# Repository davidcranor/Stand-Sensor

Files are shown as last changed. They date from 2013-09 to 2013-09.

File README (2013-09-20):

Stand-Sensor

Design files for accelerometer-based sitting/standing sensor and electrolaminate driver.  Built on Leaflabs' Maple.

Make sure that you have my hacked up version of the Wire library installed, as we need repeated start I2C. To install
it, make  backup of the old files and copy my Wire.cpp and Wire.h over them in the 

MapleIDE.app/Contents/Resources/Java/libraries/Wire/

directory (If you're on Mac).  This is a gross hack, sorry.
  
When uploading firmware, remember to build/install the Maple Mini target.

BOM is here:
https://docs.google.com/spreadsheet/ccc?key=0AkMyKIrUOd24dHlMcE16TWFrMjVCWlNEYzV1VXQ2dXc&usp=sharing

David Cranor
September 2013
cranor at media .mit dot edu

v1 notes/errata:

-DO NOT connect VCC-GND side of the switch when populating.
-USB port not close enough to edge on PCB
-Fix R12 to not trigger under-voltage protection when running off of battery power.  See datasheet for TPS61200.
-Fix mounting hole pattern to actually be symmetrical
-The leakage current in the currently specced D1 is too high, which caused some problems with the NFET power
 source switch.  Get one with a reasonable leakage current on next order.
-The PCB is slightly larger than the slot on the enclosure will allow.

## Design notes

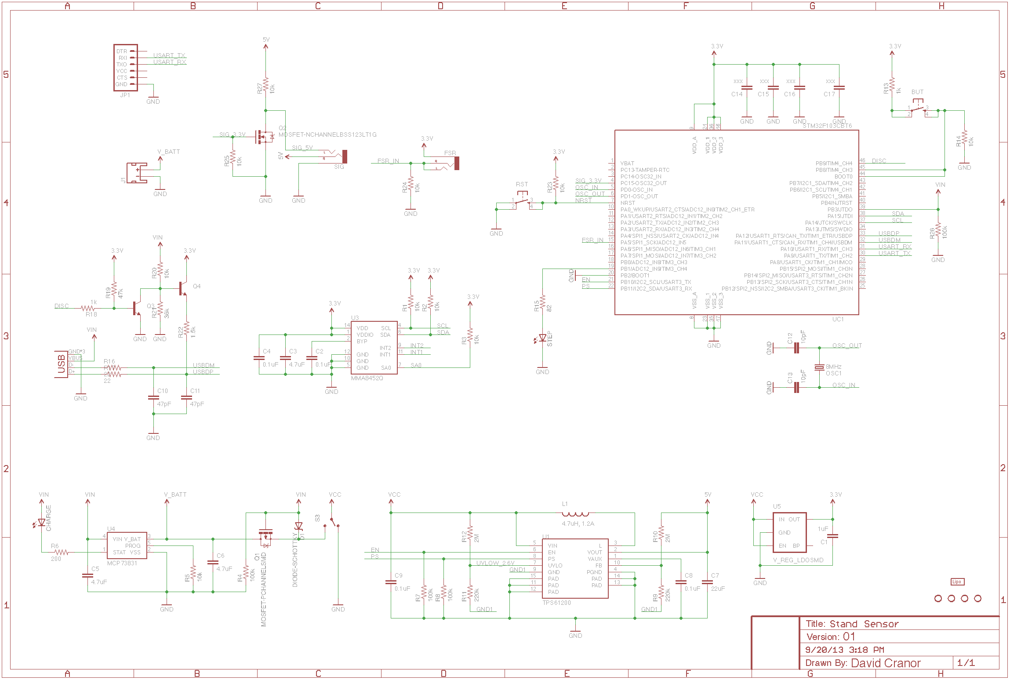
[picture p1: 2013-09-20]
Hardware/Stand Sensor.png

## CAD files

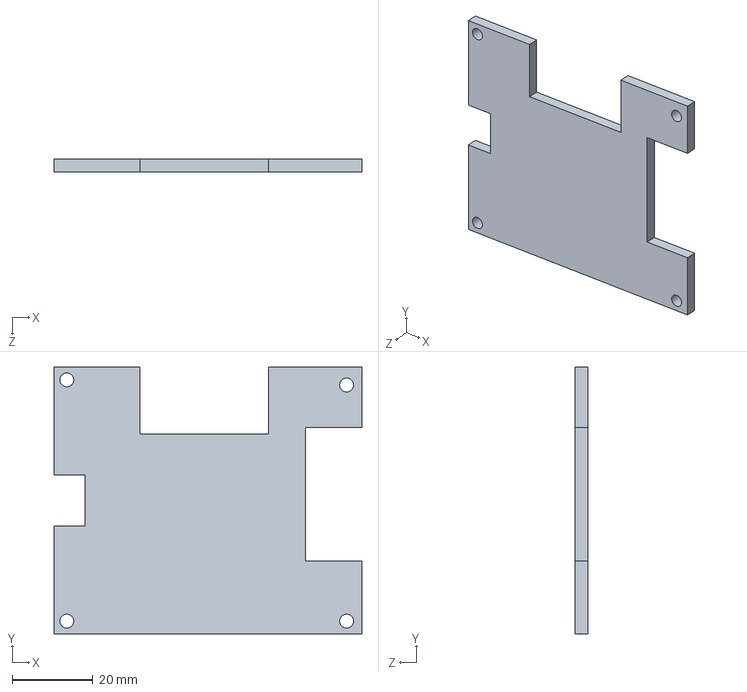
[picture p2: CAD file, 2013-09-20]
Enclosure/Stand Sensor Top Plate.SLDPRT
76.2 x 66.0 x 3.17 mm

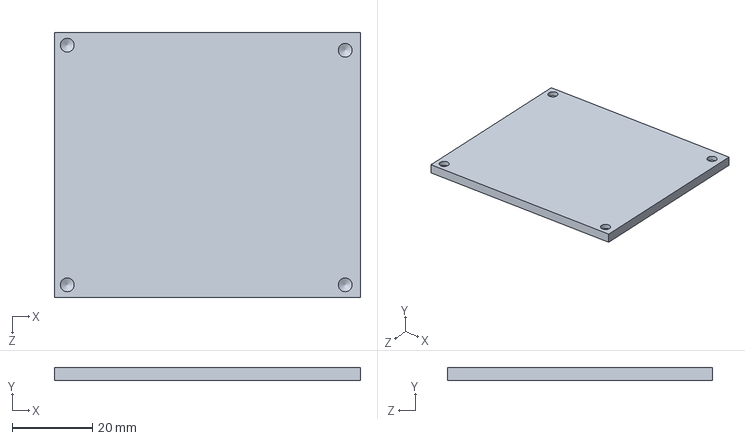
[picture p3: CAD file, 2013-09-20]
Enclosure/Stand Sensor Bottom Plate.SLDPRT
76.2 x 3.17 x 66.0 mm

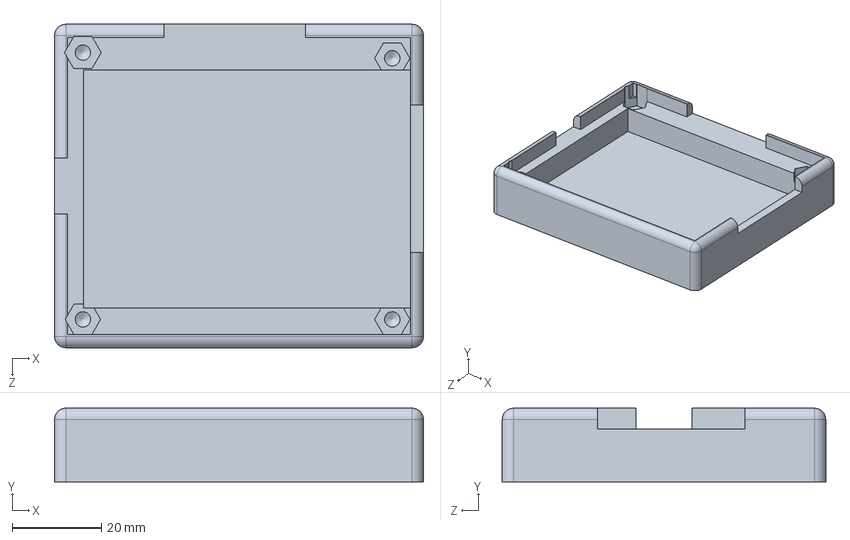
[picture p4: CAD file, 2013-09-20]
Enclosure/Stand Sensor Case.SLDPRT
82.5 x 16.5 x 72.4 mm

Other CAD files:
Enclosure/Stand Sensor Bottom Plate.DXF
Enclosure/Stand Sensor Bottom Plate.SLDDRW
Enclosure/Stand Sensor Case.STL
Enclosure/Stand Sensor Top Plate.DXF
Enclosure/Stand Sensor Top Plate.SLDDRW

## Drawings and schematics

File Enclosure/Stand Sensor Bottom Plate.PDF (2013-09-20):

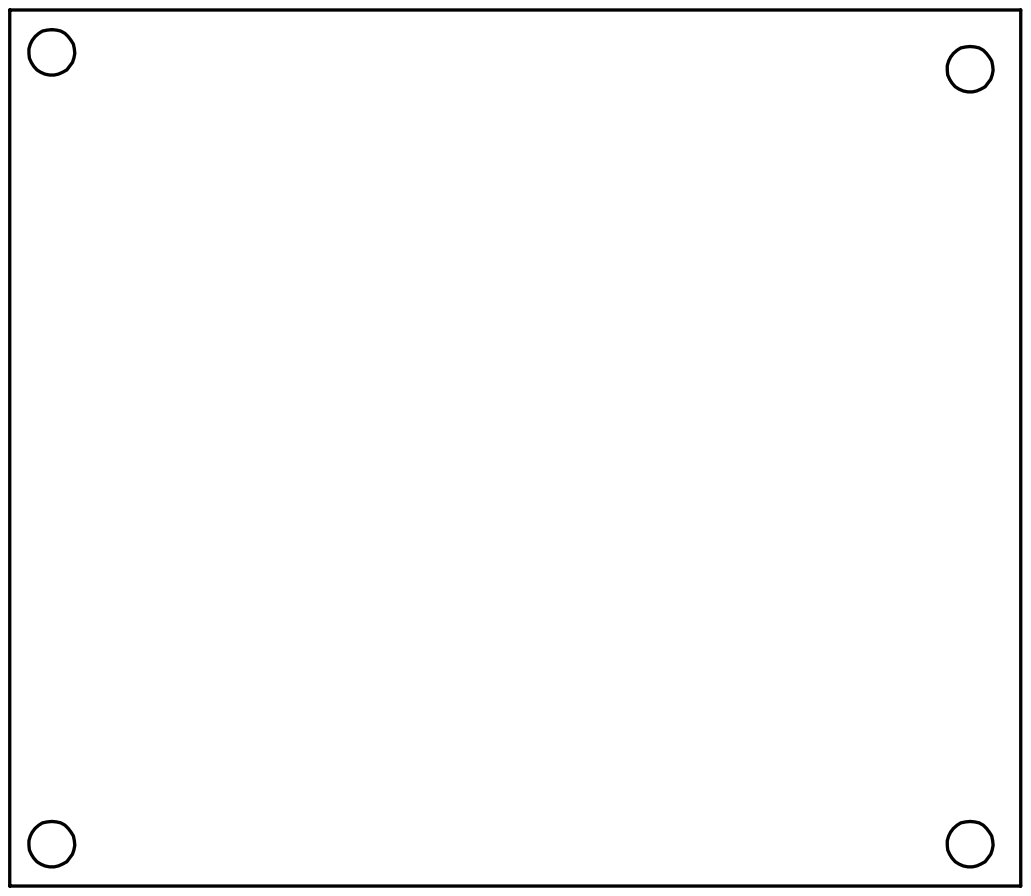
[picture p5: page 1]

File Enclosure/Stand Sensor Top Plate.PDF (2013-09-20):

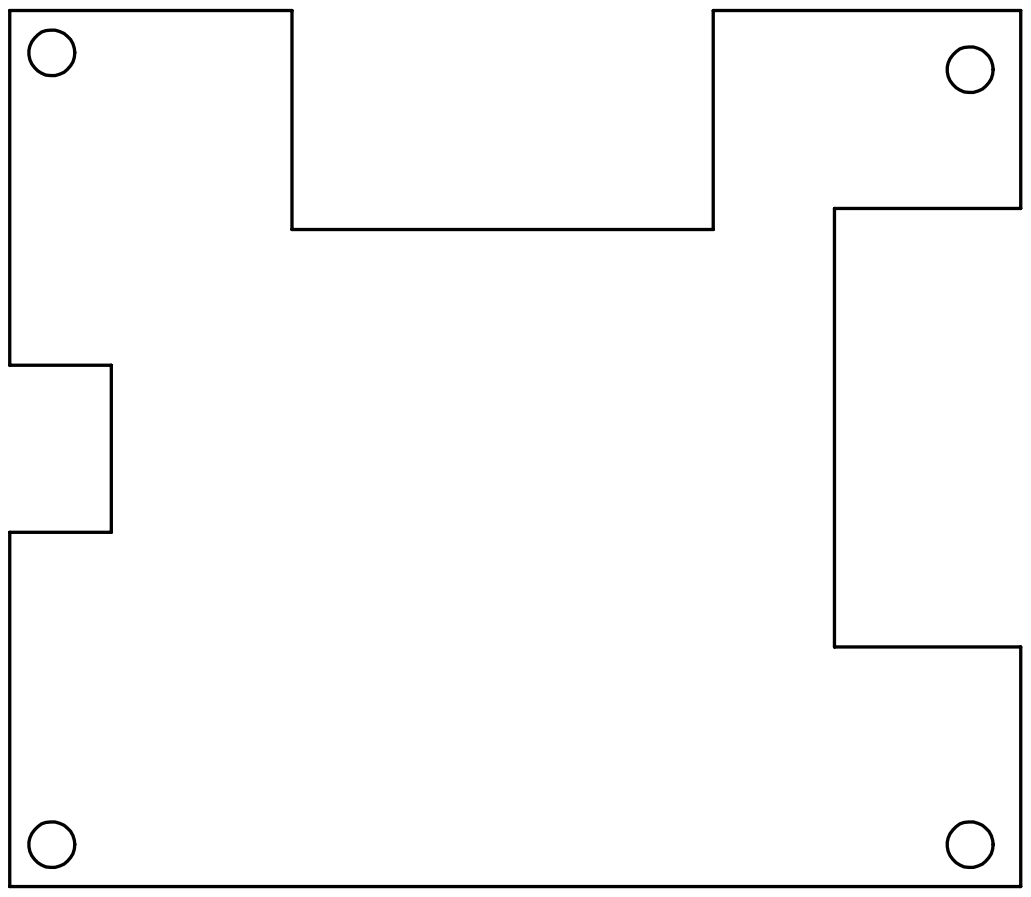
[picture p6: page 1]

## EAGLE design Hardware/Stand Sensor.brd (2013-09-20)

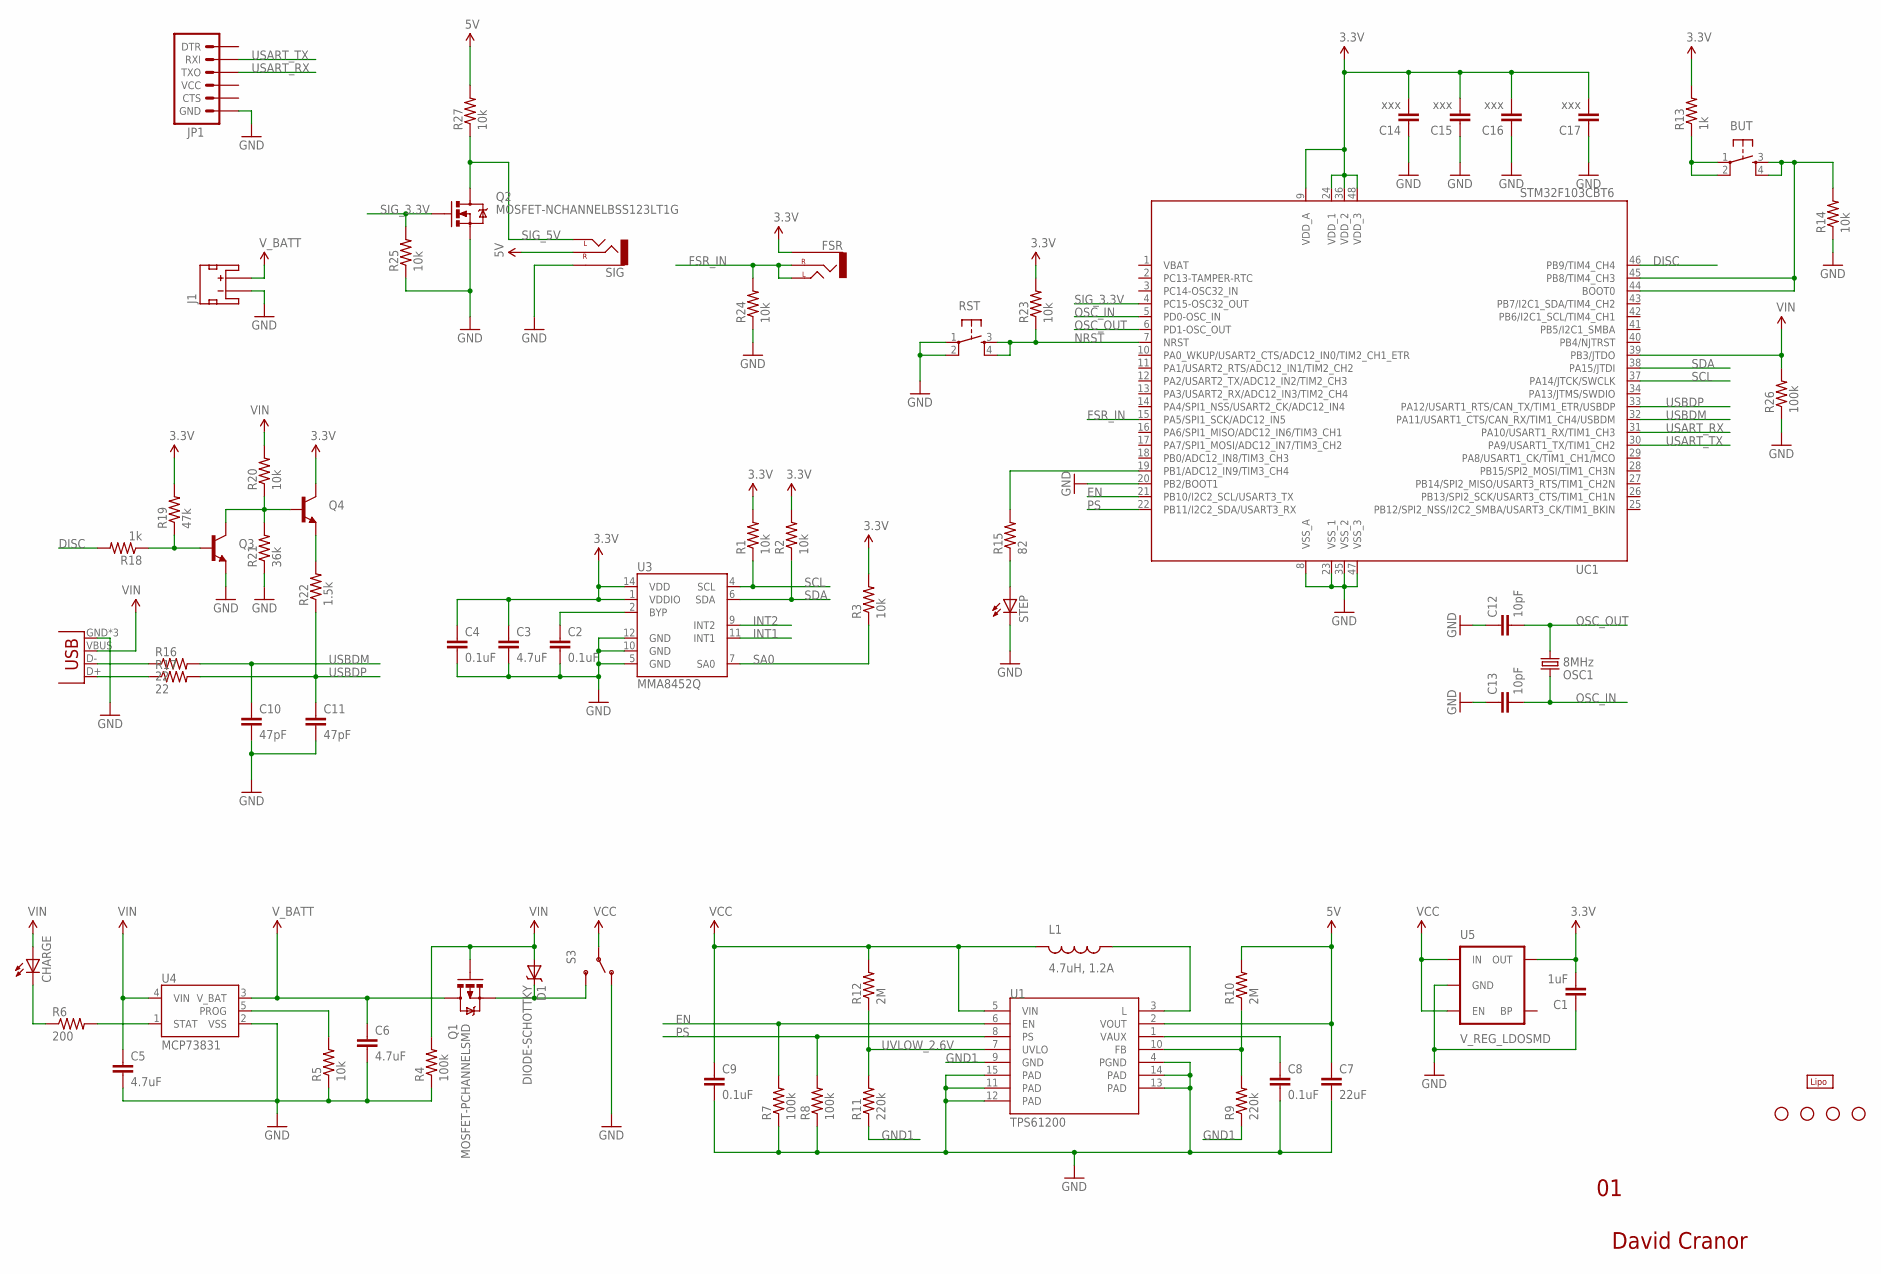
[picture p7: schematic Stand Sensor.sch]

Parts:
BUT: TAC_SWITCHSMD; TACTILE_SWITCH_SMD
C1: 1uF; 1206
C2, C4, C8, C9: 0.1uF; 1206
C3, C5, C6: 4.7uF; 1206
C7: 22uF; 1206
C10, C11: 47pF; 1206
C12, C13: 10pF; 1206
C14, C15, C16, C17: xxx; 1206
CHARGE: LED1206; LED-1206
D1: DIODE-SCHOTTKY; SOD-523
FSR: AUDIO-JACKPTH; AUDIO-JACK
J1: JST_2MM_MALE; JST-2-SMD
JP1: ARDUINO_SERIAL_PROGRAMSMD; 1X06-SMD
L1: 4.7uH, 1.2A; CDRH2D09
OSC1: 8MHz; CRYSTAL-SMD-5X3
Q1: MOSFET-PCHANNELSMD; SOT23-3
Q2: MOSFET-NCHANNELBSS123LT1G; SOT23
Q3, Q4: TRANSISTOR_NPNSOT23; SOT23
R1, R2, R3, R5, R14, R20, R23, R24, R25, R27: 10k; 1206
R4, R7, R8, R26: 100k; 1206
R6: 200; 1206
R9, R11: 220k; 1206
R10, R12: 2M; 1206
R13, R18: 1k; 1206
R15: 82; 1206
R16, R17: 22; 1206
R19: 47k; 1206
R21: 36k; 1206
R22: 1.5k; 1206
RST: TAC_SWITCHSMD; TACTILE_SWITCH_SMD
S3: SWITCH-SPDTSMD; AYZ0202
SIG: AUDIO-JACKPTH; AUDIO-JACK
STANDOFF1, STANDOFF2, STANDOFF3, STANDOFF4: STAND-OFF
STEP: LED1206; LED-1206
U1: TPS61200; QFN-10_PAD
U3: MMA8452Q; QFN-16_0.5MM
U4: MCP73831; SOT23-5
U5: V_REG_LDOSMD; SOT23-5
U$1: LIPO-OUTLINE2000; LIPO-2000
UC1: STM32F103CBT6; LQFP48
USB: USB-MICROB

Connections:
3.3V: C1.2, C3.1, C4.1, C14.2, C15.2, C16.2, C17.2, FSR.SLEEVE, Q4.3 (C), R1.2, R2.2, R3.2, R13.2, R19.2, R23.2, U3.1 (VDDIO), U3.14 (VDD), U5.5 (OUT), UC1.9 (VDD_A), UC1.24 (VDD_1), UC1.36 (VDD_2), UC1.48 (VDD_3)
5V: C7.1, R10.2, R27.2, SIG.RING (RIGHT), U1.2 (VOUT)
D+: R17.1, USB.D+
D-: R16.1, USB.D-
DISC: R18.2, UC1.46 (PB9/TIM4_CH4)
EN: R7.2, U1.6 (EN), UC1.21 (PB10/I2C2_SCL/USART3_TX)
FSR_IN: FSR.RING (RIGHT), FSR.TIP (LEFT), R24.2, UC1.15 (PA5/SPI1_SCK/ADC12_IN5)
GND: C1.1, C2.2, C3.2, C4.2, C5.2, C6.2, C7.2, C8.2, C9.2, C10.2, C11.2, C12.1, C13.1, C14.1, C15.1, C16.1, C17.1, J1.1 (-), JP1.6 (GND), Q2.2 (S), Q3.2 (E), R4.1, R5.1, R7.1, R8.1, R14.1, R21.1, R24.1, R25.1, R26.1, RST.1, RST.2, S3.1 (O), SIG.SLEEVE, STEP.C, U1.4 (PGND), U1.11 (PAD), U1.12 (PAD), U1.13 (PAD), U1.14 (PAD), U1.15 (PAD), U3.5 (GND), U3.10 (GND), U3.12 (GND), U4.2 (VSS), U5.2 (GND), UC1.8 (VSS_A), UC1.20 (PB2/BOOT1), UC1.23 (VSS_1), UC1.35 (VSS_2), UC1.47 (VSS_3), USB.GND, USB.MT1 (GND), USB.MT2 (GND)
GND1: R9.1, R11.1, U1.9 (GND)
INT1: U3.11 (INT1)
INT2: U3.9 (INT2)
unnamed: C2.1, U3.2 (BYP)
unnamed: L1.P$1 (1), U1.3 (L)
unnamed: R5.2, U4.5 (PROG)
unnamed: R6.2, U4.1 (STAT)
unnamed: CHARGE.C, R6.1
unnamed: D1.C, Q1.2 (S), S3.3 (S)
unnamed: C8.1, U1.1 (VAUX)
unnamed: R9.2, R10.1, U1.10 (FB)
unnamed: R15.2, UC1.19 (PB1/ADC12_IN9/TIM3_CH4)
unnamed: BUT.3, BUT.4, R14.2, UC1.44 (BOOT0), UC1.45 (PB8/TIM4_CH3)
unnamed: R15.1, STEP.A
unnamed: BUT.1, BUT.2, R13.1
unnamed: Q3.1 (B), R18.1, R19.1
unnamed: Q3.3 (C), Q4.1 (B), R20.1, R21.2
unnamed: Q4.2 (E), R22.2
NRST: R23.1, RST.3, RST.4, UC1.7 (NRST)
OSC_IN: C13.2, OSC1.3 (2), UC1.5 (PD0-OSC_IN)
OSC_OUT: C12.2, OSC1.1, UC1.6 (PD1-OSC_OUT)
PS: R8.2, U1.8 (PS), UC1.22 (PB11/I2C2_SDA/USART3_RX)
SA0: R3.1, U3.7 (SA0)
SCL: R1.1, U3.4 (SCL), UC1.37 (PA14/JTCK/SWCLK)
SDA: R2.1, U3.6 (SDA), UC1.38 (PA15/JTDI)
SIG_3.3V: Q2.1 (G), R25.2, UC1.4 (PC15-OSC32_OUT)
SIG_5V: Q2.3 (D), R27.1, SIG.TIP (LEFT)
USART_RX: JP1.3 (TXO), UC1.31 (PA10/USART1_RX/TIM1_CH3)
USART_TX: JP1.2 (RXI), UC1.30 (PA9/USART1_TX/TIM1_CH2)
USBDM: C10.1, R16.2, UC1.32 (PA11/USART1_CTS/CAN_RX/TIM1_CH4/USBDM)
USBDP: C11.1, R17.2, R22.1, UC1.33 (PA12/USART1_RTS/CAN_TX/TIM1_ETR/USBDP)
UVLOW_2.6V: R11.2, R12.1, U1.7 (UVLO)
VBAT: UC1.1 (VBAT)
VCC: C9.1, L1.P$2 (2), R12.2, S3.2, U1.5 (VIN), U5.1 (IN), U5.3 (EN)
VIN: C5.1, CHARGE.A, D1.A, Q1.1 (G), R4.2, R20.2, R26.2, U4.4 (VIN), UC1.39 (PB3/JTDO), USB.VBUS
V_BATT: C6.1, J1.2 (+), Q1.3 (D), U4.3 (V_BAT)

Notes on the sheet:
David Cranor

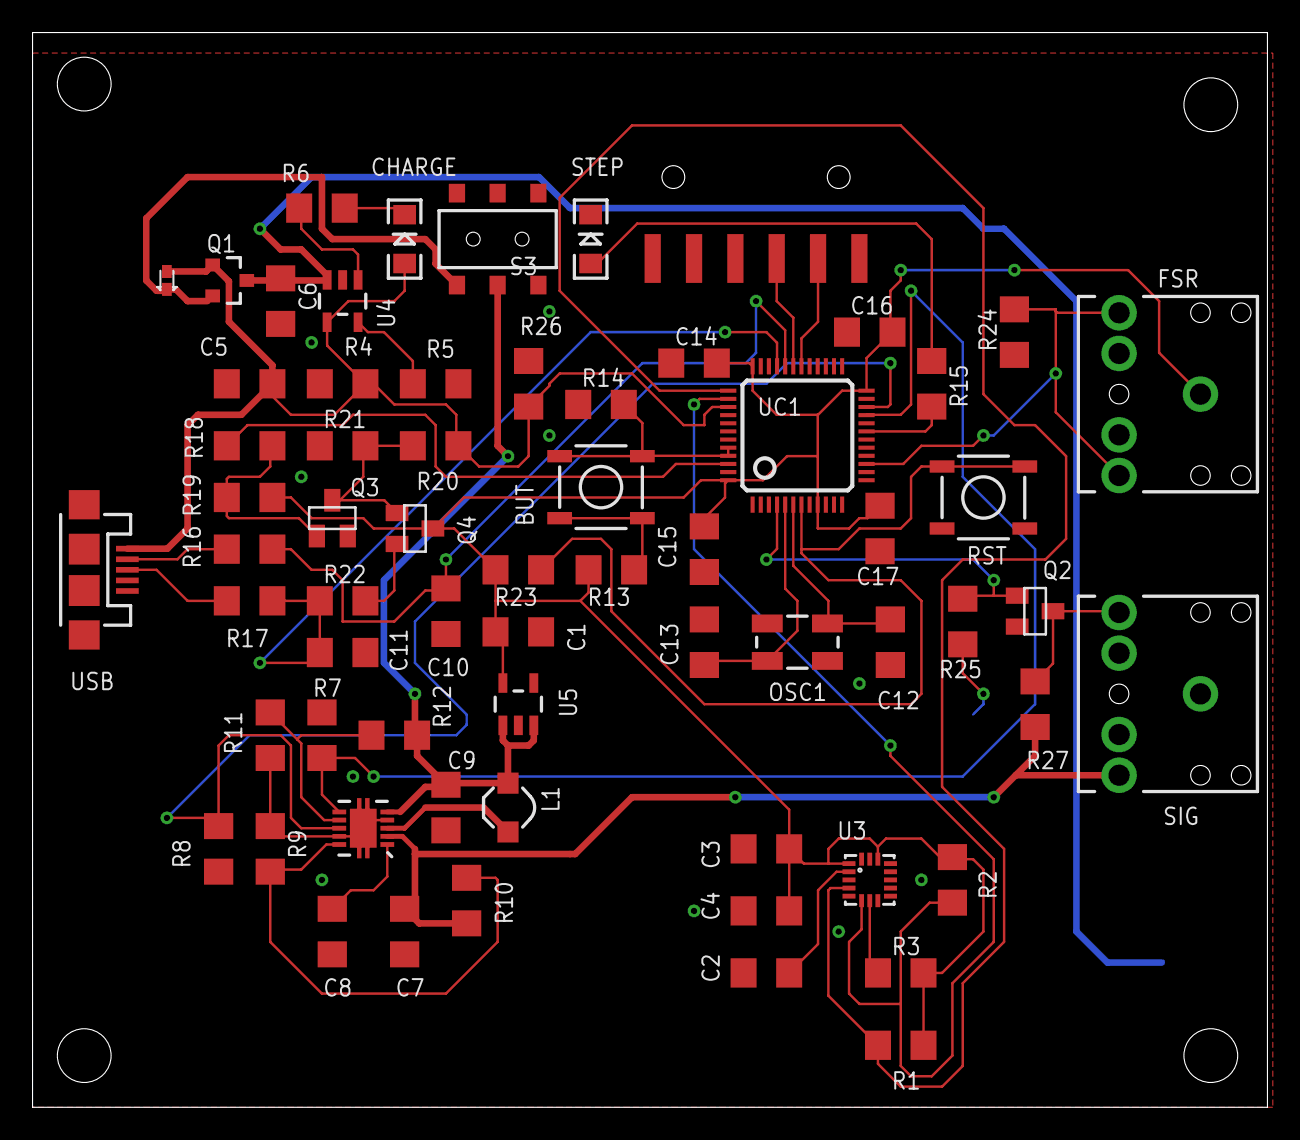
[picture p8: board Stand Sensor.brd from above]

Board: 2 copper layers, 75.9 x 66.0 mm, 71 parts (1 on the bottom side), 41 nets.

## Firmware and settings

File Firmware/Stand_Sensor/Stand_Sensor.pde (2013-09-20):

/**********************************************************
Firmware for accelerometer-based sit/stand sensor and 
electrolaminate driver

NOTES:
 
-Make sure that you have my hacked up version of
 the Wire library installed, as we need repeated start I2C.
 To insatll it, make  backup of the old files and copy my 
 Wire.cpp and Wire.h over them in the
 MapleIDE.app/Contents/Resources/Java/libraries/Wire/
 directory (If you're on Mac).
 
 This is a gross hack, sorry.
  
 -When uploading firmware, remember to build/install
  the Maple Mini target.
  
by David Cranor
cranor@media.mit.edu
9.20.2013
***********************************************************/

#include <Wire.h> // Used for I2C
#include "MMA8452.h"

//Enable/disable debug output.  Only enable when connected to computer
//and reading termainal output.  Things get weird if you try
//to print to the USB terminal without opening the port in terminal first.
int DEBUG = 0;

//Moving average buffer
int BUFFER_LENGTH = 16;

//Determined emperically in debug mode
//Strap enclosure to outside of left thigh, phono jacks facing up.
int X_THRESHOLD = 1400;

//Output LED and serial debug data framerate, 30Hz
int OUTPUT_PERIOD_US = 33333;

//Sample framerate, 120Hz
int SAMPLE_PERIOD_US = 8333;

//Blinky LED
int LED_PIN = BOARD_LED_PIN;

//5V output driver, inverted signal
int OUTPUT_PIN = 12;

//5V supply control
int EN_PIN = 1;
int PS_PIN = 0;

//Not used
int POWER_SENSE_PIN = 19;
int FSR_PIN = 6;

int rawAccel[3];  // x/y/z raw accelerometer values. 12 bits.
int accelBuffer[3][16];  //Dimension must match BUFFER_LENGTH
int bufferPointer = 0;
int averageAccel[3];

HardwareTimer outputTimer(1);
HardwareTimer sampleTimer(2);

void setup()
{

  //Delay 2 seconds to give a chance to open serial window for debugging
  delay(2000);

  //Configure pins
  pinMode(LED_PIN, OUTPUT);
  pinMode(OUTPUT_PIN, OUTPUT);
  pinMode(POWER_SENSE_PIN, INPUT);
  pinMode(FSR_PIN, INPUT_ANALOG);
  pinMode(EN_PIN, OUTPUT);
  pinMode(PS_PIN, OUTPUT);

  //Turn on the 5V supply, turn off driver output
  digitalWrite(EN_PIN, HIGH);
  digitalWrite(OUTPUT_PIN, HIGH);

  //Join the bus as a master
  Wire.begin(); 

  //Test and intialize the MMA8452
  initMMA8452(); 

  //Init the timers and timer interrupts
  initTimers();  

}

void loop()
{

  if(standDetected())
  {

    //Activate output driver
    digitalWrite(OUTPUT_PIN, LOW);

  } else {

    digitalWrite(OUTPUT_PIN, HIGH);

  }

}

void initTimers()
{

  //********OUTPUT TIMER SETUP************

  //Setup the output timer
  outputTimer.pause();

  //Set up period
  outputTimer.setPeriod(OUTPUT_PERIOD_US); //in microseconds

  // Set up an interrupt on channel 1
  outputTimer.setChannel1Mode(TIMER_OUTPUT_COMPARE);
  outputTimer.setCompare(TIMER_CH1, 1);  // Interrupt 1 count after each update
  outputTimer.attachCompare1Interrupt(handler_UI_update);

  // Refresh the timer's count, prescale, and overflow
  outputTimer.refresh();

  // Start the timer counting
  outputTimer.resume();

  //********SAMPLE TIMER SETUP**********

  //Set up the sampling/averaging timer
  sampleTimer.pause();

  //Set up period
  sampleTimer.setPeriod(SAMPLE_PERIOD_US); //in microseconds

  // Set up an interrupt on channel 1
  sampleTimer.setChannel1Mode(TIMER_OUTPUT_COMPARE);
  sampleTimer.setCompare(TIMER_CH1, 1);  // Interrupt 1 count after each update
  sampleTimer.attachCompare1Interrupt(handler_sensors_update);

  // Refresh the timer's count, prescale, and overflow
  sampleTimer.refresh();

  // Start the timer counting
  sampleTimer.resume();
}

int standDetected()
{

  if(averageAccel[0] >= X_THRESHOLD)
  {
    return 1;
  }  

  return 0;
}

void handler_sensors_update()
{  

  int total;

  //Read the x/y/z adc values and add them to circular buffer
  readAccelData(rawAccel);  

  for(int i = 0; i < 3; i++)
  {
    accelBuffer[i][bufferPointer] = rawAccel[i];

    bufferPointer = bufferPointer + 1;
    if(bufferPointer >= BUFFER_LENGTH)
    {
      bufferPointer = 0;
    }

  }

  //update the moving average
  for(int i = 0; i < 3; i++)
  {

    total = 0;

    for(int j = 0; j < BUFFER_LENGTH; j++)
    {
      total = total + accelBuffer[i][j];
    }

    averageAccel[i] = total / BUFFER_LENGTH;

  }
}


void handler_UI_update()
{

  if(standDetected())
  {

    digitalWrite(LED_PIN, HIGH);

  } else {

    digitalWrite(LED_PIN, LOW);

  }

  if(DEBUG)
  {  
    
    for (int i = 0 ; i < 3 ; i++)
    {
      SerialUSB.print(averageAccel[i]);  // Print g values (full 16 bits)
      SerialUSB.print('\t');
    }
    
  }

  if(DEBUG)
  {
    SerialUSB.println();
  }  

}

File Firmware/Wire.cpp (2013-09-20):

/******************************************************************************
 * The MIT License
 *
 * Copyright (c) 2010 LeafLabs LLC.
 * HACKED UP BY DAVID CRANOR TO SUPPORT REPEATED START I2C.
 * NOT TESTED FOR OTHER CASES, OBSCURE COMMENTS TO AID
 * ONGOING TESTING.
 *
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
 * THE SOFTWARE IS PROVIDED "AS IS", WITHOUT WARRANTY OF ANY KIND,
 * EXPRESS OR IMPLIED, INCLUDING BUT NOT LIMITED TO THE WARRANTIES OF
 * MERCHANTABILITY, FITNESS FOR A PARTICULAR PURPOSE AND
 * NONINFRINGEMENT. IN NO EVENT SHALL THE AUTHORS OR COPYRIGHT HOLDERS
 * BE LIABLE FOR ANY CLAIM, DAMAGES OR OTHER LIABILITY, WHETHER IN AN
 * ACTION OF CONTRACT, TORT OR OTHERWISE, ARISING FROM, OUT OF OR IN
 * CONNECTION WITH THE SOFTWARE OR THE USE OR OTHER DEALINGS IN THE
 * SOFTWARE.
 *****************************************************************************/

/**
 *  @brief Wire library, ported from Arduino. Provides a simplistic
 *  interface to i2c.
 */

#include "Wire.h"
#include "wirish.h"

/* low level conventions:
 * - SDA/SCL idle high (expected high)
 * - always start with i2c_delay rather than end
 */
uint32 i2c_delay = 1;

uint8 debug_pin = 0;

void i2c_start(Port port) {
    I2C_DELAY;
    digitalWrite(port.sda,LOW);
    I2C_DELAY;
    digitalWrite(port.scl,LOW);
}

void i2c_stop(Port port) {
    
    //THIS APPEARS TO GIVE PROPER WAVEFORMS
    I2C_DELAY;
    digitalWrite(port.scl,LOW);
    I2C_DELAY;
    digitalWrite(port.sda,LOW);
    

    //digitalWrite(debug_pin, HIGH);

    I2C_DELAY;
    digitalWrite(port.scl,HIGH);
    I2C_DELAY;
    digitalWrite(port.sda,HIGH);


    //digitalWrite(debug_pin, HIGH);
}

boolean i2c_get_ack(Port port) {
    I2C_DELAY;
    digitalWrite(port.scl,LOW);
    I2C_DELAY;
    digitalWrite(port.sda,HIGH);
    I2C_DELAY;
    digitalWrite(port.scl,HIGH);
    I2C_DELAY;

    if (!digitalRead(port.sda)) {
      I2C_DELAY;
      digitalWrite(port.scl,LOW);
      return true;
    } else {
      I2C_DELAY;
      digitalWrite(port.scl,LOW);
      return false;
    }
}

void i2c_send_ack(Port port) {
    I2C_DELAY;
    digitalWrite(port.sda,LOW);
    I2C_DELAY;
    digitalWrite(port.scl,HIGH);
    I2C_DELAY;
    digitalWrite(port.scl,LOW);
}

void i2c_send_nack(Port port) {
    I2C_DELAY;
    digitalWrite(port.sda,HIGH);
    I2C_DELAY;
    digitalWrite(port.scl,HIGH);
}

uint8 i2c_shift_in(Port port) {
    uint8 data = 0;

    int i;
    for (i=0;i<8;i++) {

        //ADDED THIS
        I2C_DELAY;
        digitalWrite(port.sda,HIGH);

        I2C_DELAY;
        digitalWrite(port.scl,HIGH);
        I2C_DELAY;
        data += digitalRead(port.sda) << (7-i);
        I2C_DELAY;
        digitalWrite(port.scl,LOW);
    }

    return data;
}

void i2c_shift_out(Port port, uint8 val) {
    int i;
    for (i=0;i<8;i++) {
        I2C_DELAY;
        digitalWrite(port.sda, !!(val & (1 << (7 - i))));
        I2C_DELAY;
        digitalWrite(port.scl, HIGH);
        I2C_DELAY;
        digitalWrite(port.scl, LOW);
    }
}

TwoWire::TwoWire() {
    i2c_delay = 0;
    rx_buf_idx = 0;
    rx_buf_len = 0;
    tx_addr = 0;
    tx_buf_idx = 0;
    tx_buf_overflow = false;
}

/*
 * Sets pins SDA and SCL to OUPTUT_OPEN_DRAIN, joining I2C bus as
 * master.  If you want them to be some other pins, use begin(uint8,
 * uint8);
 */
void TwoWire::begin() {
    begin(SDA, SCL);
}

/*
 * Joins I2C bus as master on given SDA and SCL pins.
 */
void TwoWire::begin(uint8 sda, uint8 scl) {
    port.sda = sda;
    port.scl = scl;
    
    //DEBUG STUFF
    pinMode(debug_pin, OUTPUT);
    digitalWrite(debug_pin, LOW);

    pinMode(scl, OUTPUT_OPEN_DRAIN);
    pinMode(sda, OUTPUT_OPEN_DRAIN);
    digitalWrite(scl, HIGH);
    digitalWrite(sda, HIGH);
}

void TwoWire::beginTransmission(uint8 slave_address) {
    tx_addr = slave_address;
    tx_buf_idx = 0;
    tx_buf_overflow = false;
    rx_buf_idx = 0;
    rx_buf_len = 0;

    //SerialUSB.print("Set up transmission to ");
    //SerialUSB.println(slave_address, HEX);
}

void TwoWire::beginTransmission(int slave_address) {
    beginTransmission((uint8)slave_address);
}

//
//  Originally, 'endTransmission' was an f(void) function.
//  It has been modified to take one parameter indicating
//  whether or not a STOP should be performed on the bus.
//  Calling endTransmission(false) allows a sketch to 
//  perform a repeated start. 
//
//  WARNING: Nothing in the library keeps track of whether
//  the bus tenure has been properly ended with a STOP. It
//  is very possible to leave the bus in a hung state if
//  no call to endTransmission(true) is made. Some I2C
//  devices will behave oddly if they do not see a STOP.
//
uint8 TwoWire::endTransmission(uint8 sendStop) {
    if (tx_buf_overflow) return EDATA;

    i2c_start(port);

    i2c_shift_out(port, (tx_addr << 1) | I2C_WRITE);
    if (!i2c_get_ack(port)) return ENACKADDR;

    // shift out the address we're transmitting to
    for (uint8 i = 0; i < tx_buf_idx; i++) {
        uint8 ret = writeOneByte(tx_buf[i]);
        if (ret) return ret;    // SUCCESS is 0
    }

    //digitalWrite(debug_pin, HIGH);

    //SerialUSB.println("Sent Data!");

    if(sendStop)
    {
        i2c_stop(port);

        //digitalWrite(debug_pin, LOW);

        //SerialUSB.println("Hung up");
    } else {


        
        //TESTY TEST TEST....problem is that lines aren't being released properly on restart condition
        //I2C_DELAY;
        //digitalWrite(port.sda,LOW);
        //I2C_DELAY;
        //digitalWrite(port.scl,LOW);
        I2C_DELAY;
        digitalWrite(port.scl,HIGH);
        //I2C_DELAY;
        //digitalWrite(port.sda,HIGH);

        //digitalWrite(debug_pin, HIGH);

        //SerialUSB.println("Not hanging up");
    }

    tx_buf_idx = 0;
    tx_buf_overflow = false;

    //

    return SUCCESS;
}

//  This provides backwards compatibility with the original
//  definition, and expected behaviour, of endTransmission
//
uint8 TwoWire::endTransmission(void)
{
  return endTransmission(true);
}
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

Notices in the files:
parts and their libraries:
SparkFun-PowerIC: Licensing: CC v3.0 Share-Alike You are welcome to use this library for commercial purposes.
